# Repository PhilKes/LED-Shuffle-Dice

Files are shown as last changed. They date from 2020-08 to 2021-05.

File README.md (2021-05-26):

# LED Shuffle Dice
### Attiny85 with Shiftregister and Accelerometer
#### Parts
* Attiny85 Microcontroller
* **74HC595** Shiftregister
* 7 **Red LEDs**
* Coin Cell Battery + Holder
* ADXL345 Accelerometer
#### Schematic
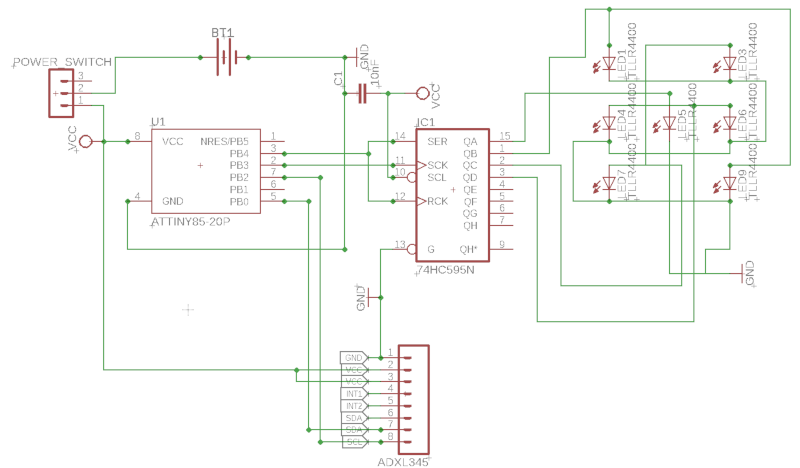
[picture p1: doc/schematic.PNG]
Schematic

* Minimal I/O Pins required (in total: 4)
* 2 Pin Connection to Shiftregister (CLK and DATA to **Attiny85** + LATCH connected to DATA)
* Accelerometer for Shake Detection
* "Shuffle" Animation
* LEDs logically connected in Pairs

#### 3D Printed Case
<p>
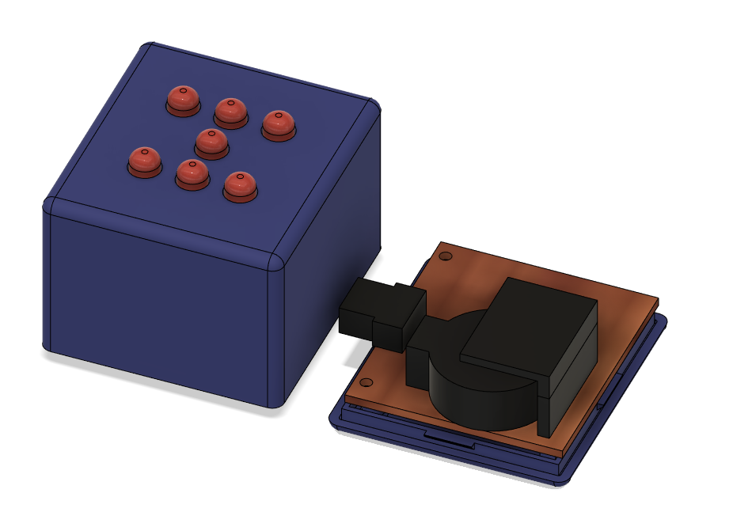
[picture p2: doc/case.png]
  
  
</p>

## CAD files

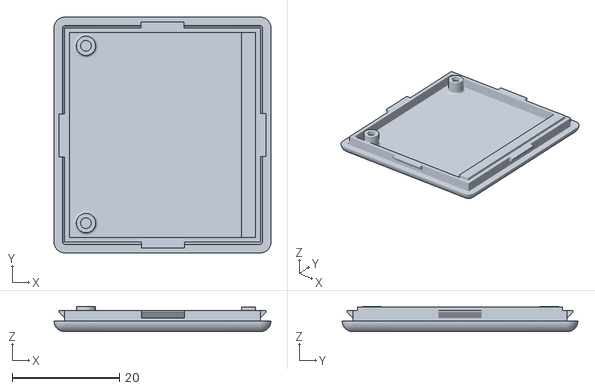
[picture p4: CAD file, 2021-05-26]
case/led_dice_bottom.stl
40.4 x 43.9 x 4.70

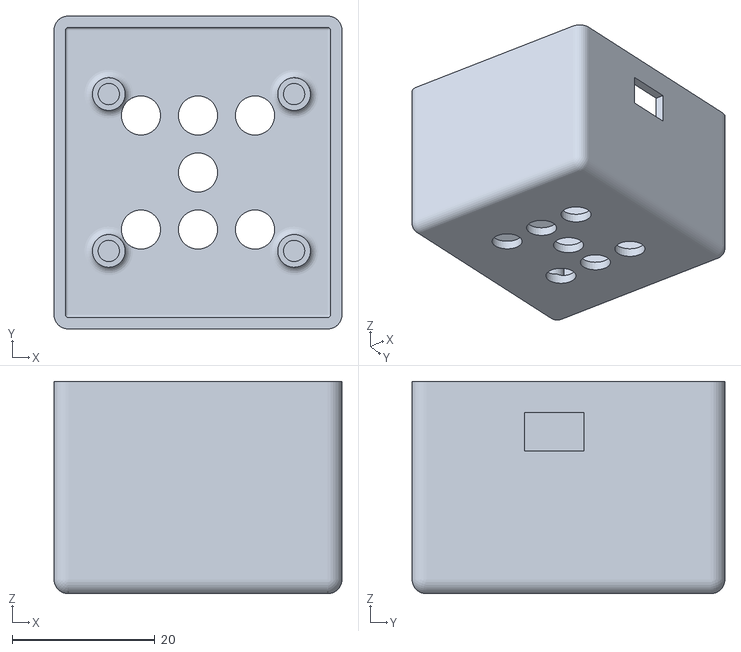
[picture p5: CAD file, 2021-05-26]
case/led_dice_top.stl
40.4 x 43.9 x 29.8

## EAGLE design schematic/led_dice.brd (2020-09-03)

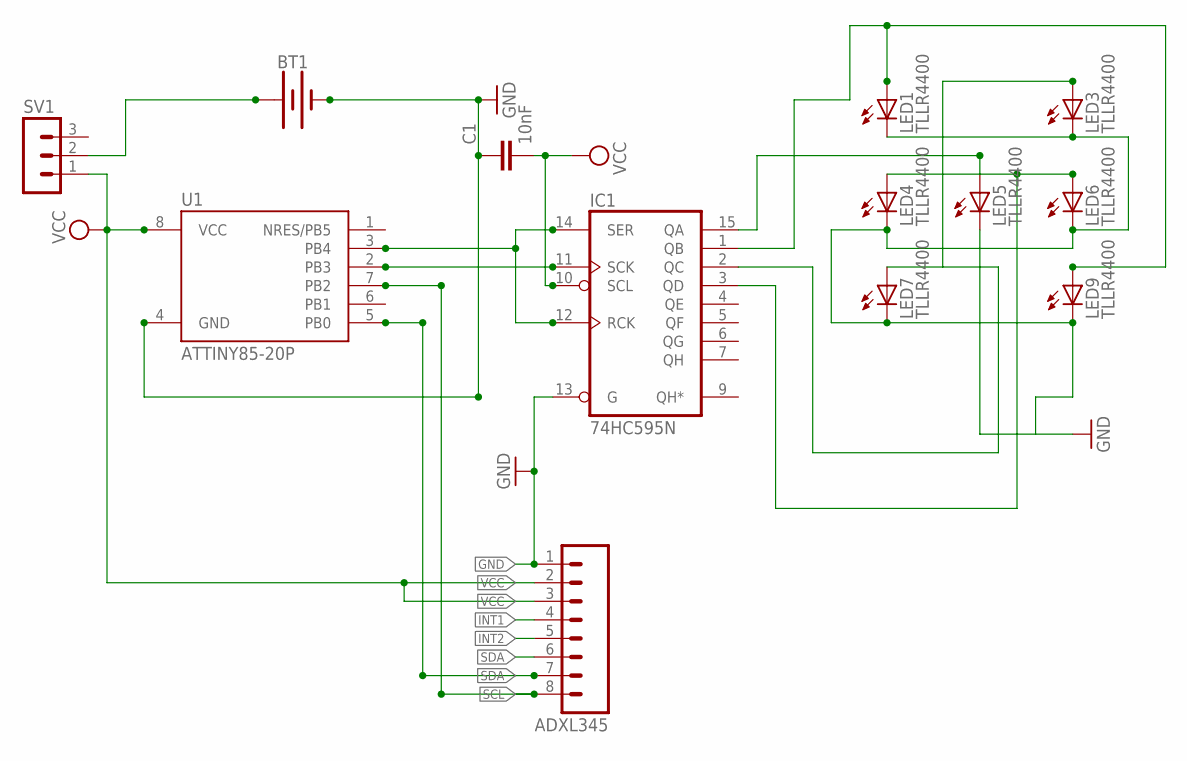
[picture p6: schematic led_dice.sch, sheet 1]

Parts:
ADXL345: M08; 1X08
BT1: BATTERY-20MM_PTH; BATTCOM_20MM_PTH
C1: 10nF; C025-024X044
IC1: 74HC595N; DIL16
LED1, LED3, LED4, LED5, LED6, LED7, LED9: TLLR4400; LED3MM
SV1: MA03-1
U1: ATTINY85-20P; PDIP08_300MIL

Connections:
GND: ADXL345.1, BT1.2 (-), C1.1, IC1.8 (GND), IC1.13 (G), LED1.K (C), LED3.K (C), LED4.K (C), LED5.K (C), LED6.K (C), LED7.K (C), LED9.K (C), U1.4 (GND)
INT1: ADXL345.4
INT2: ADXL345.5
unnamed: IC1.1 (QB), LED1.A, LED9.A
unnamed: IC1.15 (QA), LED5.A
unnamed: IC1.11 (SCK), U1.2 (PB3)
unnamed: IC1.3 (QD), LED4.A, LED6.A
unnamed: BT1.1 (+), SV1.2
unnamed: IC1.2 (QC), LED3.A, LED7.A
unnamed: IC1.12 (RCK), IC1.14 (SER), U1.3 (PB4)
SCL: ADXL345.8, U1.7 (PB2)
SDA: ADXL345.7, U1.5 (PB0)
VCC: ADXL345.2, ADXL345.3, C1.2, IC1.10 (SCL), IC1.16 (VCC), SV1.1, U1.8 (VCC)

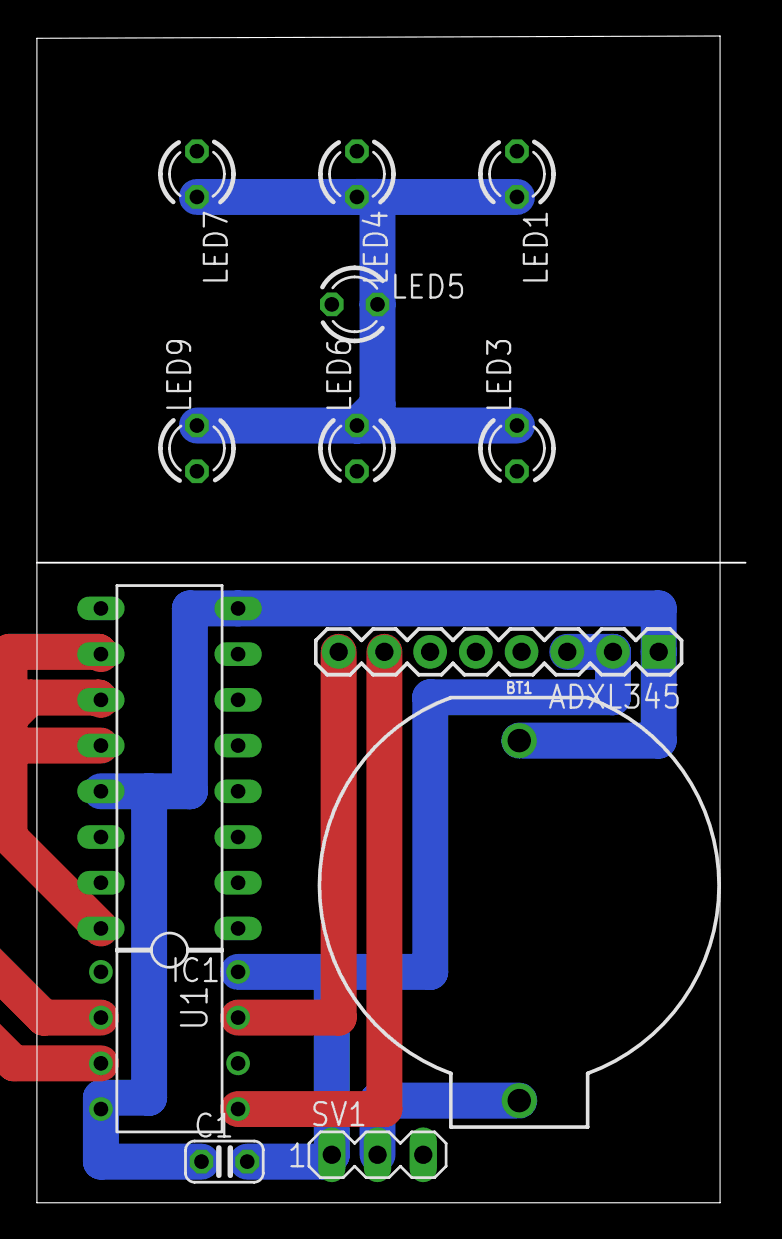
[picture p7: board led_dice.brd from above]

Board: 2 copper layers, 39.4 x 64.8 mm, 13 parts (0 on the bottom side), 11 nets.

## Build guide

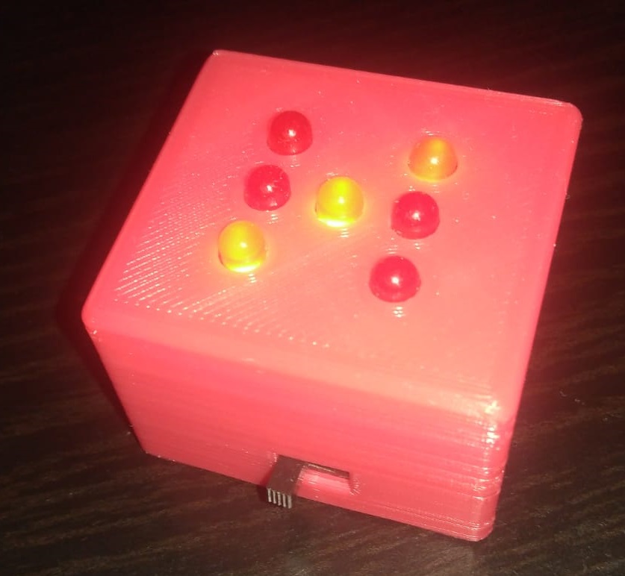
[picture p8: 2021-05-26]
doc/case_print.jpeg

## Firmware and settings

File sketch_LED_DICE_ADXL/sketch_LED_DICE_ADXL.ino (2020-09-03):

// https://github.com/PhilKes/LED_Roll_Dice
// Attiny85 + 74HC595 + ADXL345
#include <TinyWireM.h>
#include <avr/power.h>

#define ROLL_THRESHOLD  16

float x, y, z;

int dataPin = PB4;
int clockPin = PB3;

/*
   Attiny - 74hc595
   PB3 - SHCP (Clock)
   PB4 - DS (Data) + STCP (Latch)
   VCC - MR
   GND - OE

   Attiny - ADXL345
   VCC - CS
   PB0 - SDA
   PB2 - SCL
*/


void setup ()
{
  pinMode(clockPin, OUTPUT);
  pinMode(dataPin, OUTPUT);
  digitalWrite(dataPin, 0);
  digitalWrite(clockPin, 0);
  randomSeed(analogRead(0));
  // Setup ADXL345
  adxl345_init();
  setLeds(0);
}

float X, Y, Z, totalAccel;

void loop()
{

  //rollDice();
  //delay(2000);

  /* for (int i = 1; i < 7; i++) {
     setLeds(i);
     delay(2000);
    }*/

  X = 0;
  Y = 0;
  Z = 0;
  for (int i = 0; i < 10; i++) {
    readAccel(&x, &y, &z);
    X += x;
    Y += y;
    Z += z;
    delay(1);
  }
  X /= 10;
  Y /= 10;
  Z /= 10;

  totalAccel = sqrt(X * X + Y * Y + Z * Z);
  if (totalAccel > ROLL_THRESHOLD) {
    delay(150);
    // Shuffle Effect
    int last = 1;
    int next = 1;
    for (int i = 0; i < 5; i++) {
      while (next == last)
        next = random(1, 7);
      last = next;
      setLeds(next);
      delay(200);
    }
    rollDice();
    delay(1700);
  }

}

byte leds = 0;
void setLeds(int number) {
  if (number == 0) {
    leds = 0;
  }
  else if (number == 1) {
    leds = B00000001;
  }
  else if (number == 2) {
    leds = B00000010;
  }
  else if (number == 3) {
    leds = B00000011;
  }
  else if (number == 4) {
    leds = B00000110;
  }
  else if (number == 5) {
    leds = B00000111;
  }
  else if (number == 6) {
    leds = B00001110;
  }
  //shiftLeds(leds);
  shiftOut(dataPin, clockPin, MSBFIRST, leds);
  digitalWrite(clockPin, 0);
  //latch with dataPin
  digitalWrite(dataPin, 0);
  delay(10);
  digitalWrite(dataPin, 1);
  delay(10);
  digitalWrite(dataPin, 0);
}

void rollDice() {
  setLeds( random(1, 7));
}

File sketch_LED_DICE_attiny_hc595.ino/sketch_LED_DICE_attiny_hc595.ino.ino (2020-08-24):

int dataPin = 0;
int clockPin = 3;

void setup () {
  pinMode(clockPin, OUTPUT);
  pinMode(dataPin, OUTPUT);
  digitalWrite(dataPin, 0);
  digitalWrite(clockPin, 0);
}

void loop()
{
  /*
  int i = 0;
  for (i = 1; i < 7; i++) {
    setLeds(i);
    delay(2000);
  }*/
   delay(2000);
   rollDice();
}
byte leds = 0;
void setLeds(int number) {
  if (number == 1) {
    leds = B10000001;
  }
  else if (number == 2) {
    leds = B10000010;
  }
  else if (number == 3) {
    leds = B10000011;
  }
  else if (number == 4) {
    leds = B10000110;
  }
  else if (number == 5) {
    leds = B10000111;
  }
  else if (number == 6) {
    leds = B10001110;
  }
  shiftLeds(leds);
}

// the heart of the program
void shiftLeds(byte dataOut) {
  int i = 0;
  int pinState;
  digitalWrite(dataPin, 0);
  digitalWrite(clockPin, 0);

  for (i = 7; i >= 0; i--)  {
    digitalWrite(clockPin, 0);
    if ( dataOut & (1 << i) ) {
      pinState = 1;
    }
    else {
      pinState = 0;
    }

    digitalWrite(dataPin, pinState);
    digitalWrite(clockPin, 1);
    digitalWrite(dataPin, 0);
  }
  //stop shifting
  digitalWrite(clockPin, 0);
  //latch with dataPin
  digitalWrite(dataPin, 1);
  delay(10);
  digitalWrite(dataPin, 0);
}
void rollDice() {
  setLeds( random(1, 7));
}

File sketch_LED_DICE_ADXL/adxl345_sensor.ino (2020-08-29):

/************************************************************************
* This program is free software; you can redistribute it and/or modify *
* it under the terms of the GNU License V2.                            *
* This program is distributed in the hope that it will be useful,      *
* but WITHOUT ANY WARRANTY; without even the implied warranty of       *
* MERCHANTABILITY or FITNESS FOR A PARTICULAR PURPOSE.  See the        *
* GNU General Public License, version 2 for more details               *
*                                                                      *
* Bare bones ADXL345 i2c example for Arduino 1.0                       *
* by Jens C Brynildsen <http://www.flashgamer.com>                     *
* This version is not reliant of any external lib                      *
* (Adapted for Arduino 1.0 from http://code.google.com/p/adxl345driver)*
*                                                                      *
* Demonstrates use of ADXL345 (using the Sparkfun ADXL345 breakout)    *
* with i2c communication. Datasheet:                                   *
* http://www.sparkfun.com/datasheets/Sensors/Accelerometer/ADXL345.pdf *
* If you need more advanced features such as freefall and tap          *
* detection, check out:                                                *
* https://github.com/jenschr/Arduino-libraries                         *
***********************************************************************/
#include <TinyWireM.h>

#define DEVICE (0x53) // Device address as specified in datasheet 
#define SENSORS_GRAVITY_STANDARD (9.80665F) // Const float
#define MG2G_MULTIPLIER (0.004) // 1 LSB represents about 3.9 mg

byte _buff[2]; // Buffer array

char POWER_CTL = 0x2D;  //Power Control Register
char DATA_FORMAT = 0x31; // Data format control
char DATAX0 = 0x32; // X-Axis Data 0
char DATAX1 = 0x33; // X-Axis Data 1
char DATAY0 = 0x34; // Y-Axis Data 0
char DATAY1 = 0x35; // Y-Axis Data 1
char DATAZ0 = 0x36; // Z-Axis Data 0
char DATAZ1 = 0x37; // Z-Axis Data 1
char BW_RATE = 0x2C;    // Data rate and power mode control

void adxl345_init()
{
  TinyWireM.begin(); // Join i2c bus (address optional for master)

  // Setup ADXL345 registers, see datahsheet to configure for your liking
  writeTo(DATA_FORMAT, B00001000); // Enable full resolution 10-bit, B3, and most sensitive 2g range, B1B0
  writeTo(BW_RATE, B00001100); // Set 400Hz output update rate - not I2C but data update rate, B4B3B2B1
  writeTo(POWER_CTL, 0); // Always be sure to zero out register, don't asume it's zero
  writeTo(POWER_CTL, B00001000); // Enter measurement mode, B4
}

void readAccel(float *x, float *y, float *z)
{
  // How many bytes to request from ADXL345 - it seems there are problems doing more than 4 bytes, keep it at 2 bytes.
  uint8_t howManyBytesToRead = 2; 
  
  // Each axis reading comes in 10 bit resolution, i.e. 2 bytes, least significat byte first!! 
  // Thus we are converting both bytes in to one int - shift bytes to align like DATAX1DATAX0
  // If the bytes seem switched from the sensor, change [1] to [0] and verse visa
  //readFrom( DATAX0, howManyBytesToRead, _buff); //read the acceleration data from the ADXL345
  //*x = ((((int)_buff[0]) << 8) | _buff[1]) * MG2G_MULTIPLIER * SENSORS_GRAVITY_STANDARD;   
  *x = read16(DATAX0) * MG2G_MULTIPLIER * SENSORS_GRAVITY_STANDARD;   

  //readFrom( DATAY0, howManyBytesToRead, _buff); //read the acceleration data from the ADXL345
  //*y = ((((int)_buff[0]) << 8) | _buff[1]) * MG2G_MULTIPLIER * SENSORS_GRAVITY_STANDARD;   
  *y = read16(DATAY0) * MG2G_MULTIPLIER * SENSORS_GRAVITY_STANDARD;   

  //readFrom( DATAZ0, howManyBytesToRead, _buff); //read the acceleration data from the ADXL345
  //*z = ((((int)_buff[0]) << 8) | _buff[1]) * MG2G_MULTIPLIER * SENSORS_GRAVITY_STANDARD;
  // Does not always seem to work - some units have a defective z-component I've noticed
  *z = read16(DATAZ0) * MG2G_MULTIPLIER * SENSORS_GRAVITY_STANDARD;   

  // Test single bit
  //if ( (_buff[0] & 0B10000000) ) digitalWrite(PB1, HIGH); 
  //else digitalWrite(PB1, LOW);
}

// Write vale to register address
void writeTo(byte address, byte val) {
  TinyWireM.beginTransmission(DEVICE);  // start transmission to device 
  TinyWireM.write(address);             // send register address
  TinyWireM.write(val);                 // send value to write
  TinyWireM.endTransmission();          // end transmission
}

// Reads num bytes starting from address register on device in to _buff array
void readFrom(byte address, int num, byte _buff[]) {
  TinyWireM.beginTransmission(DEVICE); // start transmission to device 
  TinyWireM.write(address);             // sends address to read from
  TinyWireM.endTransmission();         // end transmission

  //TinyWireM.beginTransmission(DEVICE); // start transmission to device
  TinyWireM.requestFrom(DEVICE, num);    // request 6 bytes from device

  int i = 0;
  while(TinyWireM.available())         // device may send less than requested (abnormal)
  { 
    _buff[i] = TinyWireM.read();    // receive a byte
    i++;
  }
 //TinyWireM.endTransmission();         // end transmission
}

// Reads 2 bytes (16bits) from first x, y, or z register
int16_t read16(byte address) {
   TinyWireM.beginTransmission(DEVICE);
   TinyWireM.write(address);             // sends address to read from
   TinyWireM.endTransmission();
   TinyWireM.requestFrom(DEVICE, 2); // request 2 bytes from device
   //return (uint16_t)(TinyWireM.read() << 8) | (TinyWireM.read()); // DATAx0DATAx1
   return (uint16_t)(TinyWireM.read() | (TinyWireM.read() << 8)); // DATAx1DATAx0
  }

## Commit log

2020-08-15 initial sketches, schematic, case added
    [dice.brd, dice.sch, dice2.brd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]
2020-08-20 case: 123Design case added + Sketch updates
    [dice_595.brd, dice_595.sch]
2020-08-29 ADXL345 Shake detection added to Sketch + Schematic updated
    [dice.brd, dice.sch, dice2.brd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]
2020-08-30 Schematic fixes
    [led_dice.brd]
2020-09-03 Sketch: added Shuffle Effect + 3d case updated
    [led_dice.brd, led_dice.sch]
2020-09-03 3D Case fixes
2021-05-26 Fusion 360 2-part case .STL Files added
    [led_dice_bottom.stl, led_dice_top.stl]

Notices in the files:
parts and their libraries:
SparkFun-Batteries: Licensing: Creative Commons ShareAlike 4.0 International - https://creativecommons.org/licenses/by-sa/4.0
